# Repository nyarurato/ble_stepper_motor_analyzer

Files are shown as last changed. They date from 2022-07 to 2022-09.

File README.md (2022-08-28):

# BLE Stepper Motor Monitor

The BLE Stepper Monitor Analyzer is a variant of the Simple Stepper Motor Analyzer which replaces the touch screen LCD with a Bluetooth BLE radio link and a python app that provides the display or a desktop computer. This result in a smaller and less expensive board and a large display that leverages on the desktop computer capabilities.

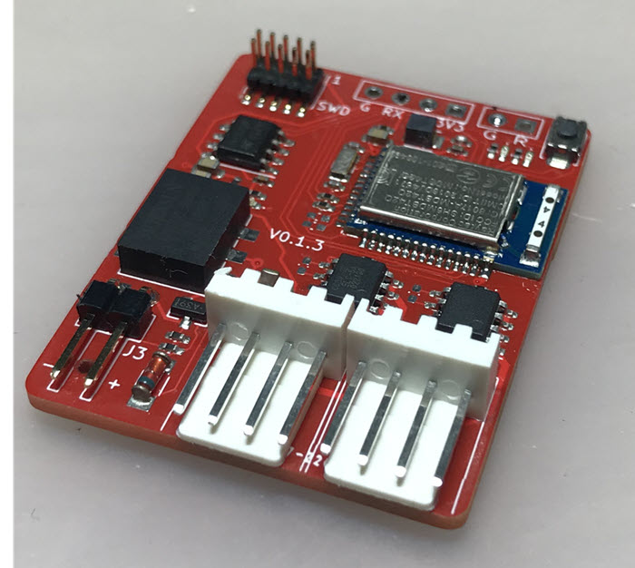
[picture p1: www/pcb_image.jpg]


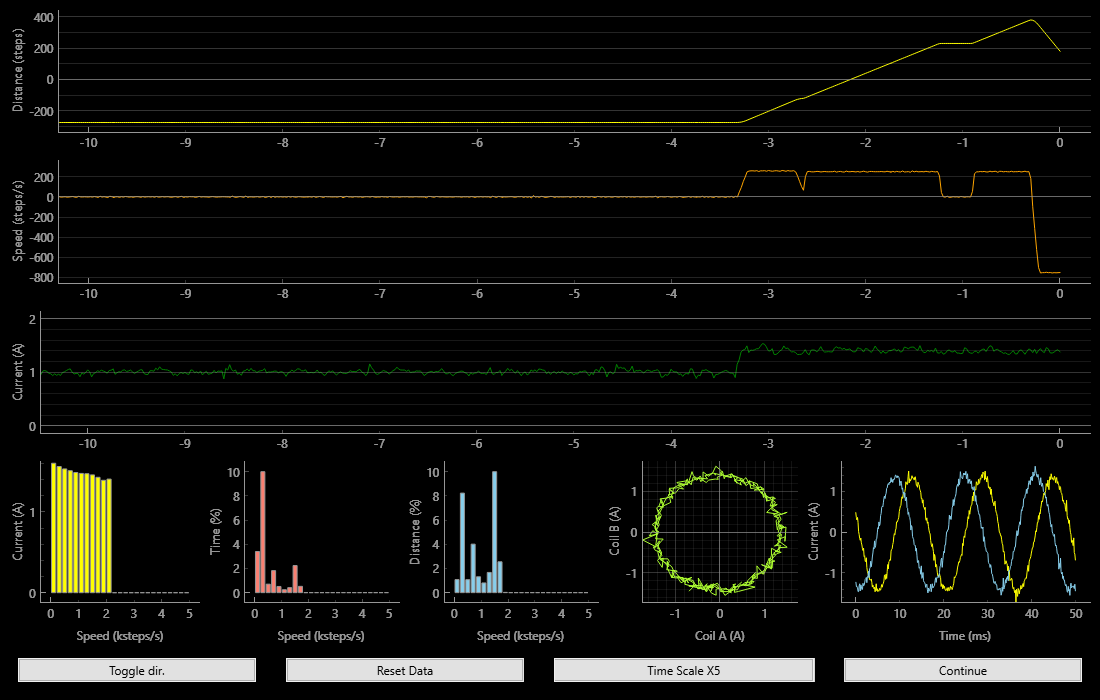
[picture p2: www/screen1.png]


## Highlights
* Open-source hardware, firmware, and software designs, with permissive license that allows commercial use and does not require attribution.
* A small and relatively inexpensive PCB that can be embedded in a 3D printer or CNC machine.
* Each PCB has a unique address and can be monitored individually.
* The PCB's can be ordered  from JLCPCB with all the parts preassembled, except for the the nrf52 BLE module that need to be soldered separately.
* The stepper motor is galvanically isolated from the analyzer's electronics which  minimizes potential interference or ground loops.
* The analyzer can be powered from any 4.5 to 30VDC source and consumes very little power, about 50mw. Even a single 9V battery can power it for many hours. Power is required only when monitoring the stepper and the stepper can be operates safely even if the PCB is not powered.

## Caveats
* At this time, updating the PCB firmware requires a programmer. Normally it can be an inexpensive Segger JLink EDU Mini, which as of Aug 2022 are unavailable due to the global supply chain shortage. A more expensive alternative is the Nordic nRF52832 DK which can act also as a Segger programmer.
* The two current sensor ICs that are available from JLCPCB have higher noise than the Alegro GMR sensors. However, the analyzer functions properly with the noisier sensors as well.
* As of Aug 2022, the python application requires some TLC, for example to recover gracefully if a wireless connection lost. However, it is fully functional and was tested on Windows and Mac OSX.
* The PCB can be built with two versions of the BLE module, one with an internal antenna and one with a U.FL connector for an external antenna. Internal antennas are 
more compact but may be insufficient with shielded 3D printers.

## Installing the PCB

* IMPORTANT: Always turn power off before connecting or disconnecting the PCB or the stepper motor.
* Connect a voltage of 4.5VDC t0 30VDC to the connector J3. Pay attention to polarity though the PCB is protected against reversed polarity. Verify that one red LED is solid while the other blinks slowly.;
* With the PCB energized and the **stepper not connected yet to the board** long press on the PCB button until the yellow LED will blink. Make sure the LED blinked exactly 3 times. This will calibrate the zero current of the sensors.
* With power off, connect the 4 wires of your stepper motor through the board such that one connector with four wires is connected to your controller and the other is connected to the stepper. The PCB is arranged such that the 4 connector pins from left to right are connected pass-through to their respective pins on the other connector. Also, the two connector are interchangeable such that each can act as an input or an output.
* Turn power on and verify that your machine functions properly and that the direction of the stepper is correct. That is, the wiring should not reverse the direction of the stepper.

## Installing and running the Python application.

1. Download the python directory this github repository.
1. Install python3 on your computer. Follow the Python installation instructions for your operating system. The analyzer requires Python 3.7 or latter but prefer the latest available python. 
1. Identify the *python* and *pip* command on your computer. On some computers they can be *python* and *pip* respectively and on others something like *python3.10& and *pip3.10* respectively. From now on we will refer to them as *python* and *pip* but replace with the actual command names as needed.
1. Verify the version of your python by running the command: **python --version**. Verify that the printed version number is at least 3.7.
1. With the PCB powered, Run the command  *python3 scanner_main.py*, after a few seconds, it will print a list of BLE devices it found. One of them should have the name that looks like STP-XXXXXXXXXXXX. Note the device
address that is printed before that name. We will use it later to access
the device.
1. Run the command **python analyzer_main.py -d <device-address>** where <device-address> is the device address you identified in the previous step. If you get errors about missing python modules such as **bleak**, install them using the pip command and try again. You can also use the
**requirements.txt** file to install all missing modules at once.
1. If everything went well, the analyzer_main.py application will connect to the device and shows its data in real time.

## Understanding the data
The screenshot below shows the 8 data items that are monitors. The data can be reset using the **Reset** button and can be paused/played using the **Pause/Continue** button. 

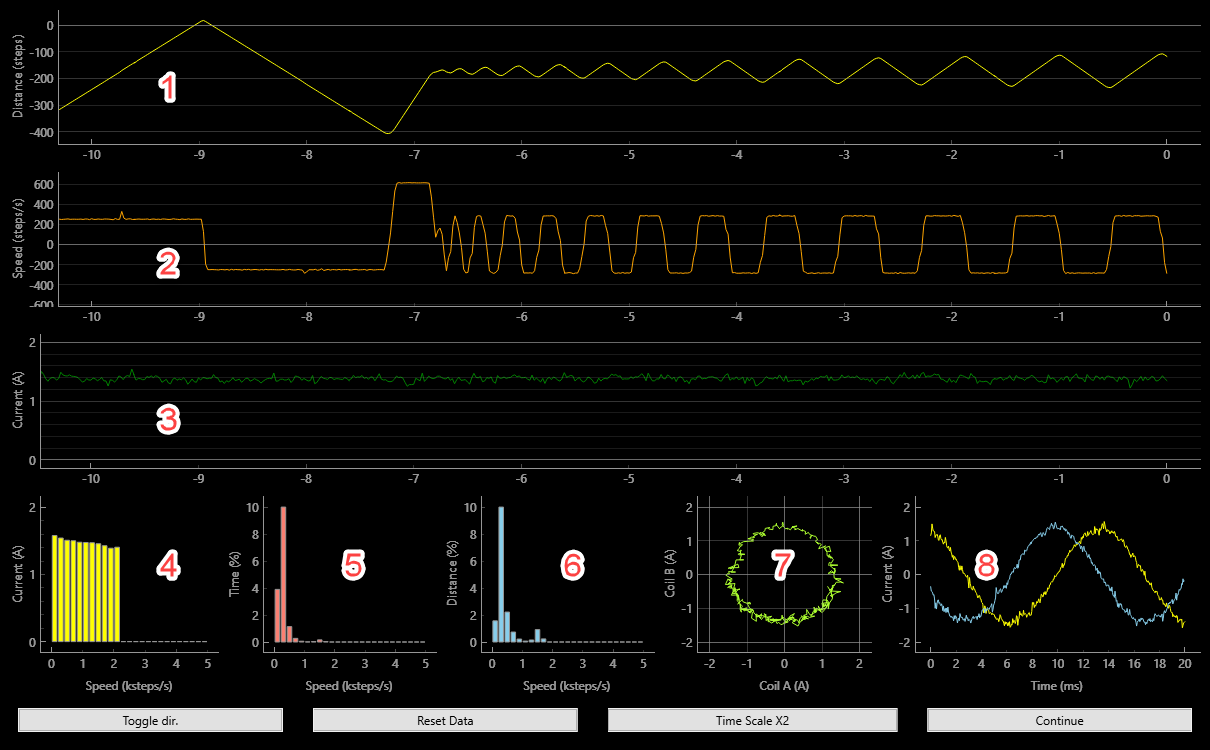
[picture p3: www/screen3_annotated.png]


1. Step counter over time. If the direction of the counting is opposite to what you would like, click on the **Toggle Dir** button. This will not effect the stepper motor but will count in the opposite direction.
2. Speed in steps/sec over time. This value is the derivative of the step counter above.
3. Stepper current in Amps over time. This value is computed as *sqrt(A^2 + B^2)* where A and B are the momentary currents in Amps in coils A, B respectively, and it represents the peak currents in each of the coils.
4. Coil peak current vs speed. This histogram shows the stepper current in different speeds. Ideally all speeds should have about the same current but too high inductance or too lower supply voltage may result in current and torque degradation in higher speeds.
5. Distance vs speed. This histogram shows in what speeds the stepper made the most distance (steps or revolutions)
6. Time vs speed. This histogram shows in what speeds the stepper was most of the time.
7. Phase pattern. This graph shows the 'cleanness' of the signal in the stepper coil. Every second of two the analyzer captures the signals in graph 8 and shows their pattern also in graph 7. Ideally graph 7 would be a circle center around the 0,0 point and its radius is the peak current set for the stepper.
8. Oscilloscope graph. This graph shows current patterns captures periodically from the two coils and ideally they should look like clean sin/cosine graphs with magnitude equal to the stepper peak current. Every cycle of the sin/cosine graph represent 4 full stepper steps. If the stepper speed is too fast or two slow to show the signals, use the Time Scale button to speed up or slow down the signal capture.

## Building your own BLE Stepper Motor Analyzer

* The three production files for JLCPCB SMD service are available under the kicad directory. This will allow you to get fully populated boards except for the BLE module.
* Solder a Raytac nrf52832 BLE module. You can use MDBT42Q-512KV2 (internal antenna) or MDBT42Q-U512KV2 (U.FL connector for an external antenna).
* Flash the board with the firmware using a compatible SWD programmer. We are using Segger's JLink with a Segger Edu Mini programmer or if this is not available, a Nordic NRF52-DK which can act also as a JLink programmer. Use a standard 2x5 pins 0.05" pitch SWD cable.
* Zero calibrate the sensors as explained above. 

## Modifying the firmware

* The source code of the firmware is available in this github repository under the platformio folder. Open that folder with the platformio IDE (a plugin for VSCode) and your project is ready.
* The PCB has a serial output for debugging. You can connect there a 115200 baud 3.3v serial/USB and view the output.
* To program the PCB use a Segger compatible debugger such as Segger Edu Mini, or Nordic nrf52 DK board. This will also allow you to debug the program, set breakpoints, single step and so on.

## FAQ

Q: Can I use this open source design in commercial products?

A: Yes, and you are welcome to do so, and attribution is not needed.

-----

Q: Can I operate the printer with the PCB connected but not powered or not monitored?

A: Yes. The electronics and the stepper are isolated from each other.

----

Q: How much does it cost to build the PCB?

A: Depending on quantities. For a batch of 30, JLCPCB changes about $7 per assembled board and then you need to add the Raytac BLE module which costs about $9. This brings the unit cost to less than $20, as of Aug 2022.

----

Q: If you would redesign it from scratch, what would you do differntly?

A: The main change would be to use ESP32 instead of the Raytac/Nordic module and this is for several reasons:

* It's less expensive.
* It has better support for firmware upgrade by the user.
* It's available from JLCPCB's SMD assembly service.

The Nordic nrf52 was selected for it's low power, with the intention to power the PCB by harvesting stepper motor power, but that requirement was dropped at a latter stages of the project.

-----

Q: How does this differs from the Simple Stepper Motor analyzer?

A: Some of the differences are:

* The lack of builtin display makes this analyzer more compact and less expensive.
* The Simple Stepper Motor analyzer is self contained with display while this one is intended to be buried in a 3D printer, using a computer for the display.
* The Simple Stepper Motor Analyzer uses a Raspberry Pi Pico processor while this one uses Nordic nRF52832.
* The Simple Stepper Motor Analyzer samples the signal at 100Khz while this one samples at 40Khz due to the limitations of the nRF52832. This however doesn't seem to matter.
* The Simple Stepper Motor Analyzer displays each graph on screen of its own while this one displays all the graphs at once.
* Having the display on a computer makes it easier to graph screenshots, for example, to post in diagnostics discussions in 3D printer forums.

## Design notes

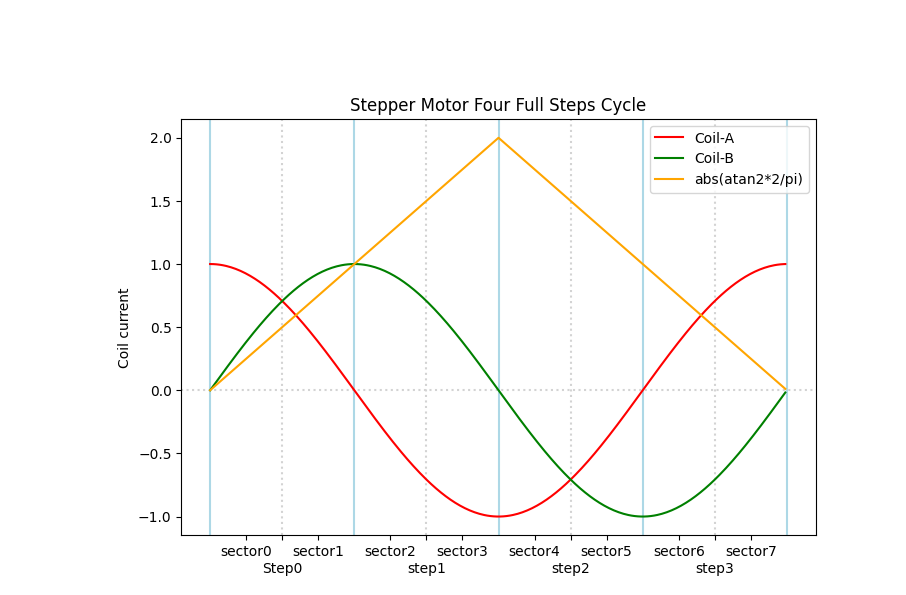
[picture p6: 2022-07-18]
docs/quadrants_plot.png

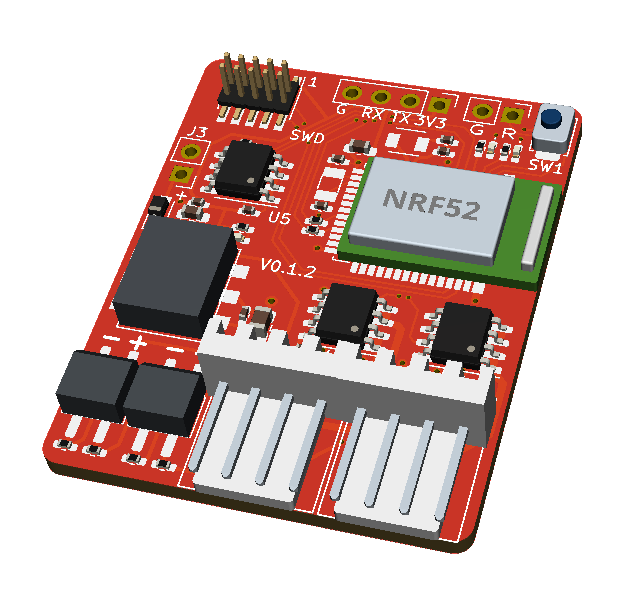
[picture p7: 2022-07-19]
docs/3d_view.png

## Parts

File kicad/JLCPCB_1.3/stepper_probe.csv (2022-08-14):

Comment | Designator | Footprint | LCSC
1u | C1 | stepper_probe:C_0402_1005Metric_Pad0.74x0.62mm_HandSolder | C52923
DNP | C13,C14 | stepper_probe:C_0402_1005Metric_Pad0.74x0.62mm_HandSolder | DNP
10u | C2,C10,C11 | stepper_probe:C_0603_1608Metric_Pad1.08x0.95mm_HandSolder | C96446
12pf | C3,C5 | stepper_probe:C_0402_1005Metric_Pad0.74x0.62mm_HandSolder | C26406
100n | C4,C6,C9,C12 | stepper_probe:C_0402_1005Metric_Pad0.74x0.62mm_HandSolder | C307331
10u 50v | C7 | stepper_probe:C_0805_2012Metric_Pad1.18x1.45mm_HandSolder | C440198
100n 50V | C8 | stepper_probe:C_0402_1005Metric_Pad0.74x0.62mm_HandSolder | C307331
LED Y | D2 | stepper_probe:LED_0402_1005Metric_Pad0.77x0.64mm_HandSolder | C165978
LED R | D1,D3 | stepper_probe:LED_0402_1005Metric_Pad0.77x0.64mm_HandSolder | C165980
5V6 | D4 | Diode_SMD:D_MiniMELF | C8062
Conn_01x04_Male | J1,J2 | stepper_probe:connector_4pins_horizontal | C31753
BAT | J3 | stepper_probe:PinHeader_1x02_P2.54mm_Horizontal_JLCPCB | C2935927
Serial Port | J4 | stepper_probe:PinHeader_1x04_P2.54mm_Vertical | DNP
SWD | J5 | stepper_probe:PinHeader_2x05_P1.27mm_Vertical_SMD | C2935458
Reset header | J6 | stepper_probe:PinHeader_1x02_P2.54mm_Vertical | DNP
10uh | L2 | stepper_probe:coil_10uh | C107342
15nh | L3 | stepper_probe:C_0402_1005Metric_Pad0.74x0.62mm_HandSolder | C27143
Motor | M1 | stepper_probe:Empty | DNP
PJA3439 | Q1 | stepper_probe:SOT-23_JLCPCB | C2844879
300k | R1 | stepper_probe:R_0402_1005Metric_Pad0.72x0.64mm_HandSolder | C25774
10K | R10 | stepper_probe:R_0402_1005Metric_Pad0.72x0.64mm_HandSolder | C25744
DNP | R11,R12 | stepper_probe:R_0402_1005Metric_Pad0.72x0.64mm_HandSolder | DNP
0R | R14,R15 | stepper_probe:R_0402_1005Metric_Pad0.72x0.64mm_HandSolder | C17168
20k | R2 | stepper_probe:R_0402_1005Metric_Pad0.72x0.64mm_HandSolder | C25765
5K1 | R5,R6,R7 | stepper_probe:R_0402_1005Metric_Pad0.72x0.64mm_HandSolder | C25905
1K | R8,R9,R16,R17 | stepper_probe:R_0402_1005Metric_Pad0.72x0.64mm_HandSolder | C11702
SW_Push | SW1 | stepper_probe:SW_Push_SPST_NO_Alps_SKRK | C720477
CC6920BSO-5A | U1,U2 | stepper_probe:SOIC-8_LCPCB_ROT | C2880430
MDBT42Q-512KV2 | U3 | stepper_probe:RAYTAC_MDBT42Q
K7803MT-500R4 | U4 | stepper_probe:Converter_DCDC | C2692194
M24C02-FMN | U5 | stepper_probe:SOIC-8_LCPCB_ROT | C7562
32.768Khz | Y1 | stepper_probe:Crystal_SMD_3215-2Pin_3.2x1.5mm | C479190

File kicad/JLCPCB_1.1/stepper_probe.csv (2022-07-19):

Comment | Designator | Footprint | LCSC
1u | C1 | stepper_probe:C_0402_1005Metric_Pad0.74x0.62mm_HandSolder | C52923
10u | C2,C10,C11 | stepper_probe:C_0603_1608Metric_Pad1.08x0.95mm_HandSolder | C96446
12pf | C3,C5 | stepper_probe:C_0402_1005Metric_Pad0.74x0.62mm_HandSolder | C26406
100n | C4,C6,C9,C12 | stepper_probe:C_0402_1005Metric_Pad0.74x0.62mm_HandSolder | C307331
10u 50v | C7 | stepper_probe:C_0805_2012Metric_Pad1.18x1.45mm_HandSolder | C440198
100n 50V | C8 | stepper_probe:C_0402_1005Metric_Pad0.74x0.62mm_HandSolder | C307331
LED Y | D2 | stepper_probe:LED_0402_1005Metric_Pad0.77x0.64mm_HandSolder | C165978
LED R | D1,D3 | stepper_probe:LED_0402_1005Metric_Pad0.77x0.64mm_HandSolder | C165980
MB1S | D4,D5 | stepper_probe:DIODE_BRIDGE | C232821
1N5819WS | D6 | stepper_probe:D_SOD-323_HandSoldering | C191023
Conn_01x04_Male | J1,J2 | stepper_probe:connector_4pins_horizontal
BAT | J3,J6 | stepper_probe:PinHeader_1x02_P2.54mm_Vertical
Serial Port | J4 | stepper_probe:PinHeader_1x04_P2.54mm_Vertical
SWD | J5 | stepper_probe:PinHeader_2x05_P1.27mm_Vertical_SMD | C2935458
10uh | L2 | stepper_probe:coil_10uh | C107342
15nh | L3 | stepper_probe:C_0402_1005Metric_Pad0.74x0.62mm_HandSolder | C27143
Motor | M1 | stepper_probe:Empty
10K | R10 | stepper_probe:R_0402_1005Metric_Pad0.72x0.64mm_HandSolder | C25744
10R | R1,R2,R3,R4 | stepper_probe:R_0402_1005Metric_Pad0.72x0.64mm_HandSolder | C25077
5K1 | R5,R6,R7 | stepper_probe:R_0402_1005Metric_Pad0.72x0.64mm_HandSolder | C25905
1K | R8,R9 | stepper_probe:R_0402_1005Metric_Pad0.72x0.64mm_HandSolder | C11702
SW_Push | SW1 | stepper_probe:SW_Push_SPST_NO_Alps_SKRK | C720477
TMCS1108A4BQDT | U1,U2 | Package_SO:SOIC-8_3.9x4.9mm_P1.27mm
MDBT42Q-512KV2 | U3 | stepper_probe:RAYTAC_MDBT42Q
K7803MT-500R4 | U4 | stepper_probe:Converter_DCDC | C2692194
M24C02-FMN | U5 | Package_SO:SOIC-8_3.9x4.9mm_P1.27mm | C7562
32.768Khz | Y1 | stepper_probe:Crystal_SMD_3215-2Pin_3.2x1.5mm | C479190

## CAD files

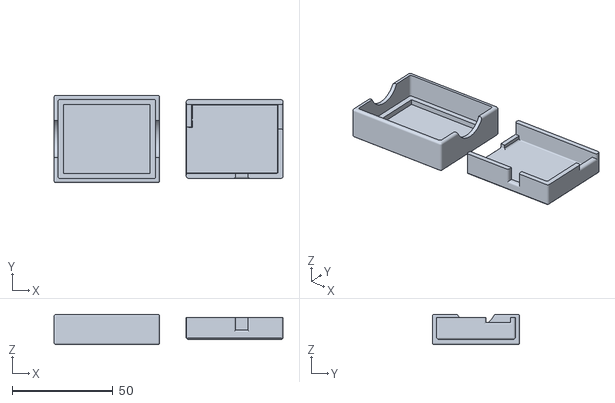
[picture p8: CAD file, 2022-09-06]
3D/ble_stepper_analyzer_case.stl
113.6 x 43.4 x 15.0

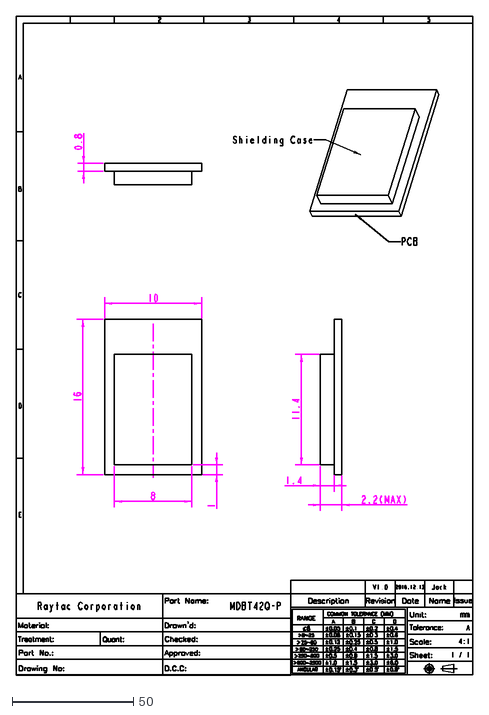
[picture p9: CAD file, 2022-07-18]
docs/MDBT42Q Footprint_Design Guide-210702/2D & 3D Drawing/MDBT42Q-P/MDBT42Q-P 2D Drawing-20170503.dxf
188.5 x 271.9

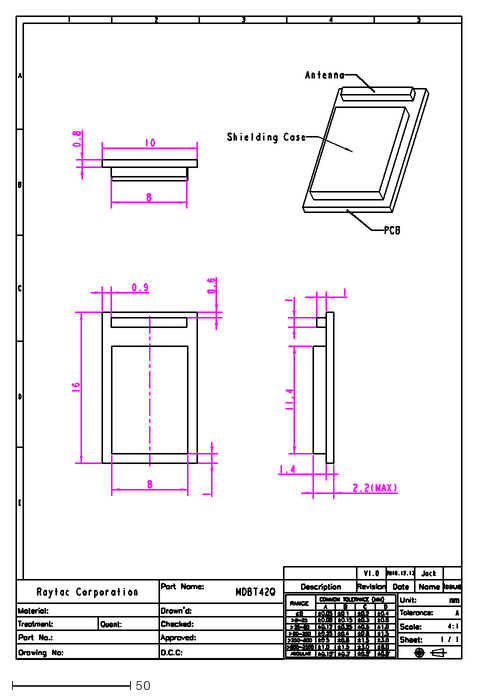
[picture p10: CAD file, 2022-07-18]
docs/MDBT42Q Footprint_Design Guide-210702/2D & 3D Drawing/MDBT42Q/MDBT42Q 2D Drawing-20170503.dxf
188.5 x 271.9

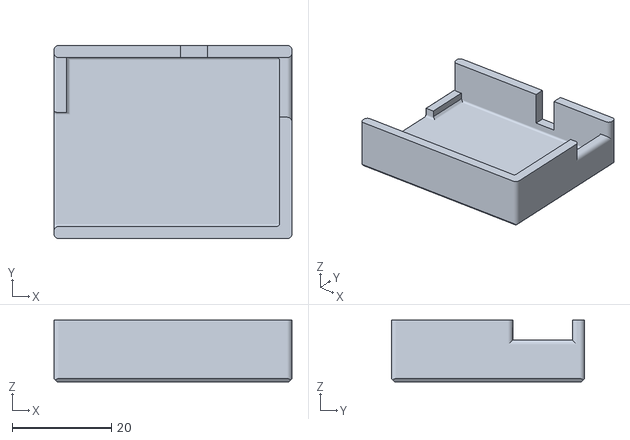
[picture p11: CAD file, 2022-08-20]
docs/stepper_probe_case.stl
48.0 x 39.0 x 12.5

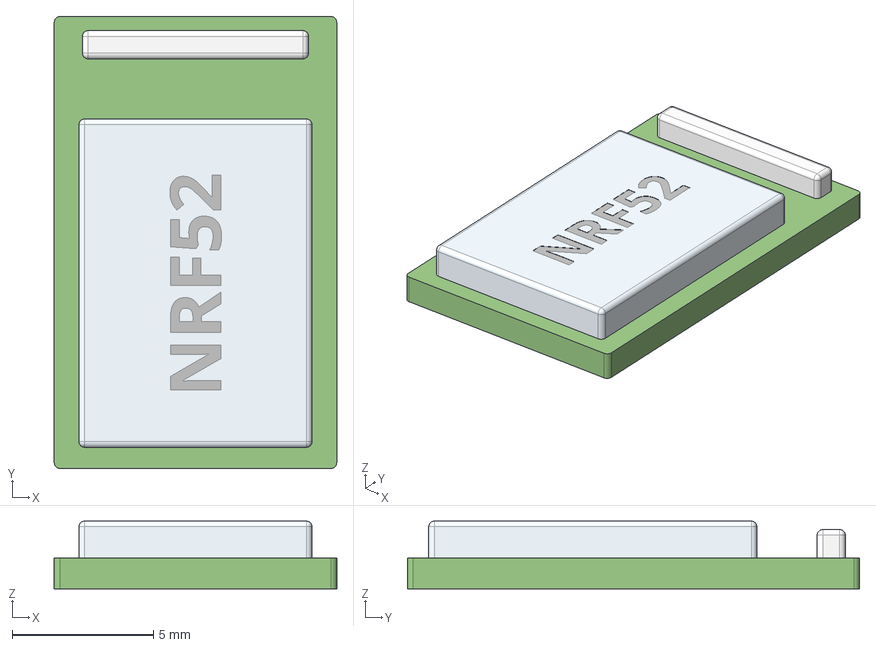
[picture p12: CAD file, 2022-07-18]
kicad/models/raytack_MDBT42Q.step
10.0 x 16.0 x 2.40 mm

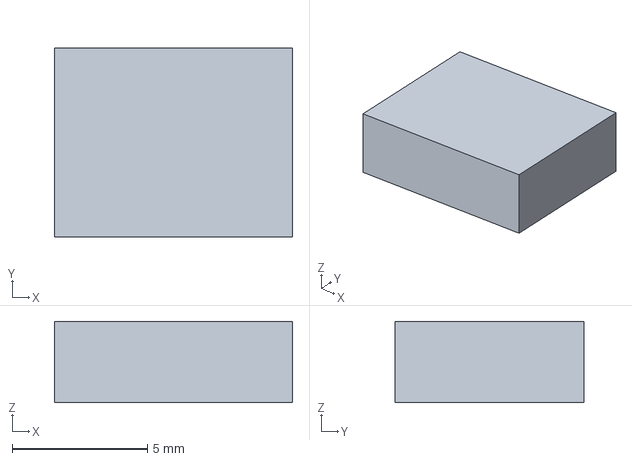
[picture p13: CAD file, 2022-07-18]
kicad/models/dc_dc_model.step
8.80 x 7.00 x 3.00 mm

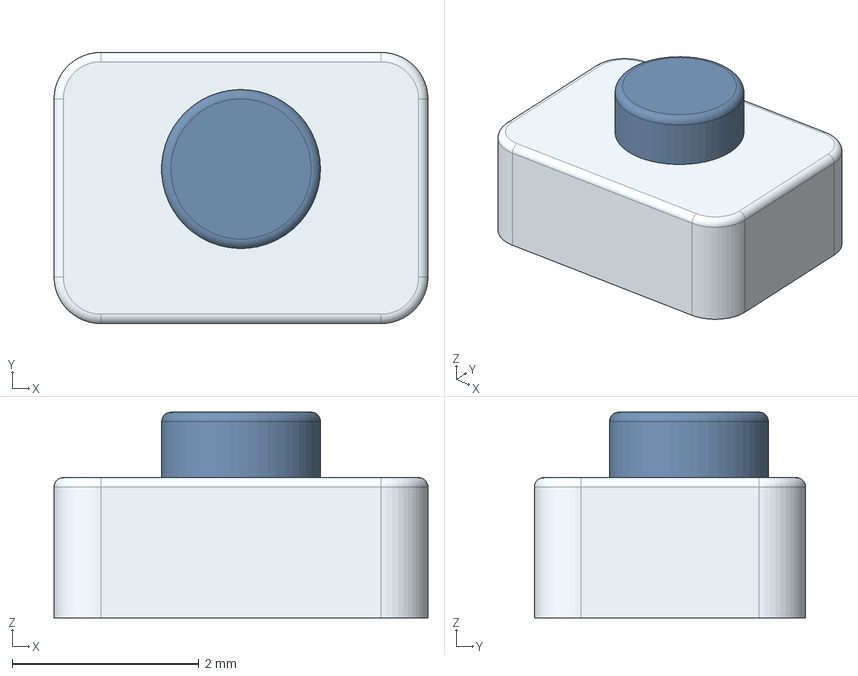
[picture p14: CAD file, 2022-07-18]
kicad/models/tactile_switch.step
4.00 x 2.90 x 2.20 mm

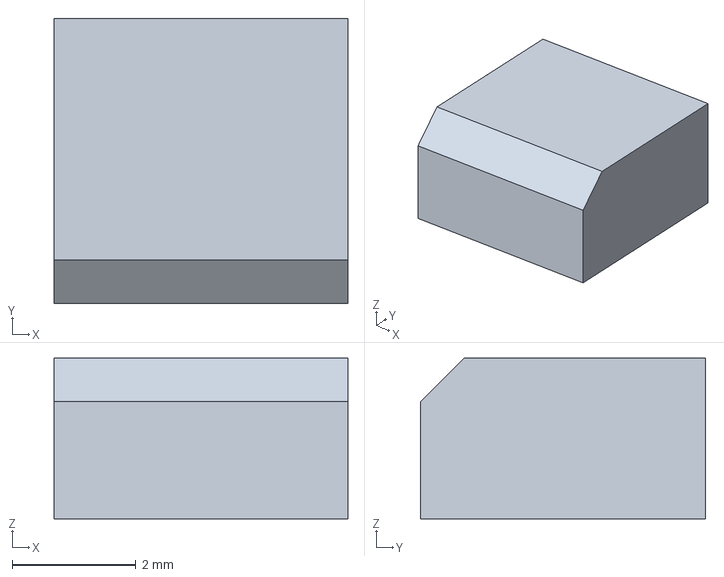
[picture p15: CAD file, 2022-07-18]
kicad/models/diode_bridge.step
4.75 x 4.60 x 2.60 mm

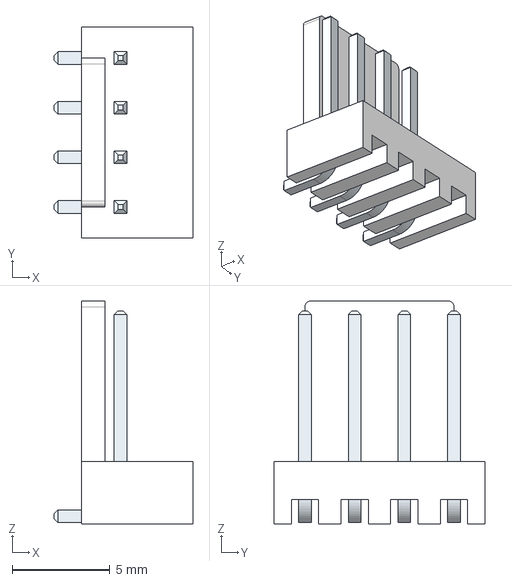
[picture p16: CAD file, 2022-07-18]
kicad/models/kf2510_4p_right_angle.step
7.10 x 10.8 x 11.4 mm

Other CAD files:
docs/MDBT42Q Footprint_Design Guide-210702/2D & 3D Drawing/MDBT42Q-P/MDBT42Q-P 2D Drawing-20170503.dwg
docs/MDBT42Q Footprint_Design Guide-210702/2D & 3D Drawing/MDBT42Q/MDBT42Q 2D Drawing-20170503.dwg

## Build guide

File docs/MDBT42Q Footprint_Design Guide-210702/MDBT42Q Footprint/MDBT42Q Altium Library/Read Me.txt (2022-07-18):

Files are compatible with Altium Designer 09

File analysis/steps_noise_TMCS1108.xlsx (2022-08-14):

Raw Steps | Normalized Steps | Normalized Squared
0.37 | 0.003592814371 | 1.290831511e-05
0.39 | 0.02 | 0.0006
0.36 | -0.01 | 4.105202768e-05
0.35 | -0.02 | 0.0003
0.37 | 0.003592814371 | 1.290831511e-05
0.41 | 0.04 | 0.0019
0.41 | 0.04 | 0.0019
0.38 | 0.01 | 0.0002
0.37 | 0.003592814371 | 1.290831511e-05
0.40 | 0.03 | 0.0011
0.35 | -0.02 | 0.0003
0.38 | 0.01 | 0.0002
0.40 | 0.03 | 0.0011
0.38 | 0.01 | 0.0002
0.36 | -0.01 | 4.105202768e-05
0.35 | -0.02 | 0.0003
0.35 | -0.02 | 0.0003
0.36 | -0.01 | 4.105202768e-05
0.36 | -0.01 | 4.105202768e-05
0.38 | 0.01 | 0.0002
0.34 | -0.03 | 0.0007
0.36 | -0.01 | 4.105202768e-05
0.38 | 0.01 | 0.0002
0.37 | 0.003592814371 | 1.290831511e-05
0.36 | -0.01 | 4.105202768e-05
0.40 | 0.03 | 0.0011
0.37 | 0.003592814371 | 1.290831511e-05
0.37 | 0.003592814371 | 1.290831511e-05
0.36 | -0.01 | 4.105202768e-05
0.35 | -0.02 | 0.0003
0.37 | 0.003592814371 | 1.290831511e-05
0.38 | 0.01 | 0.0002
0.39 | 0.02 | 0.0006
0.37 | 0.003592814371 | 1.290831511e-05
0.38 | 0.01 | 0.0002
0.38 | 0.01 | 0.0002
0.36 | -0.01 | 4.105202768e-05
0.38 | 0.01 | 0.0002
0.37 | 0.003592814371 | 1.290831511e-05
0.35 | -0.02 | 0.0003
0.38 | 0.01 | 0.0002
0.36 | -0.01 | 4.105202768e-05
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

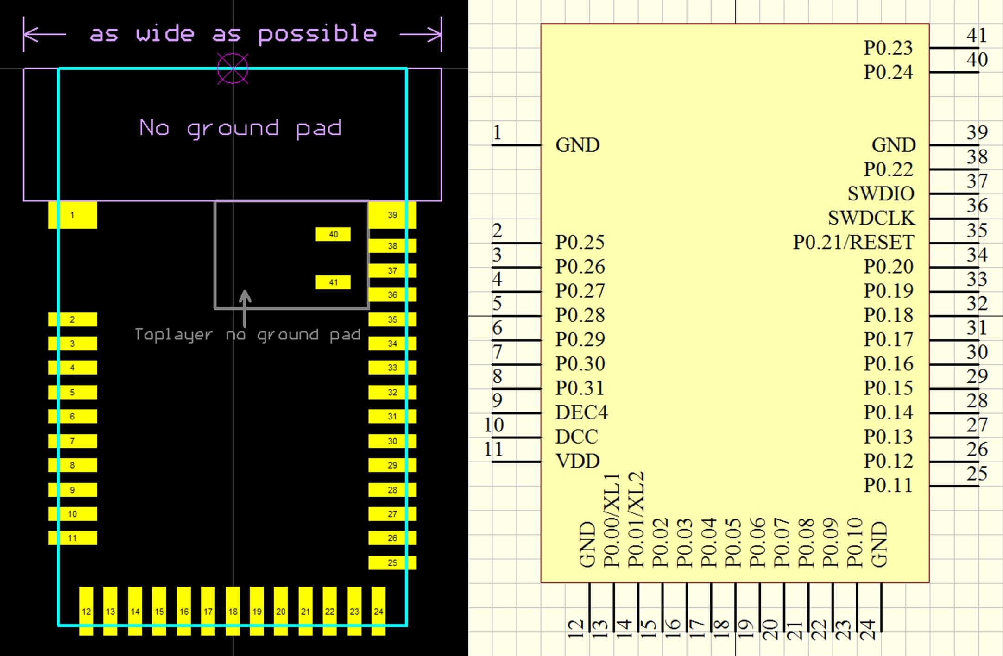
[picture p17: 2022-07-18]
docs/MDBT42Q Footprint_Design Guide-210702/MDBT42Q Footprint/MDBT42Q Protel Library/MDBT42Q Protel Library-210702.jpg

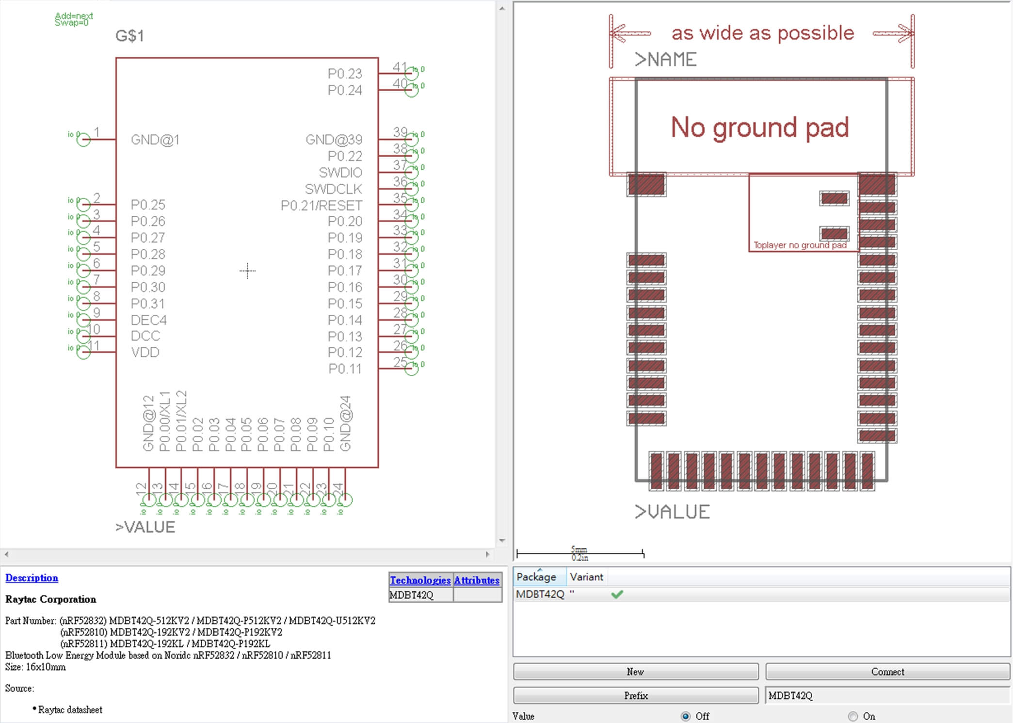
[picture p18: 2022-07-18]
docs/MDBT42Q Footprint_Design Guide-210702/MDBT42Q Footprint/MDBT42Q Eagle Library/MDBT42Q Eagle Library-210702.jpg

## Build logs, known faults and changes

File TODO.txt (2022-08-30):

* [Device] Avoid step counter drift when stepper is not energized.

* [Python] Add text display of steps and currents.

---------------

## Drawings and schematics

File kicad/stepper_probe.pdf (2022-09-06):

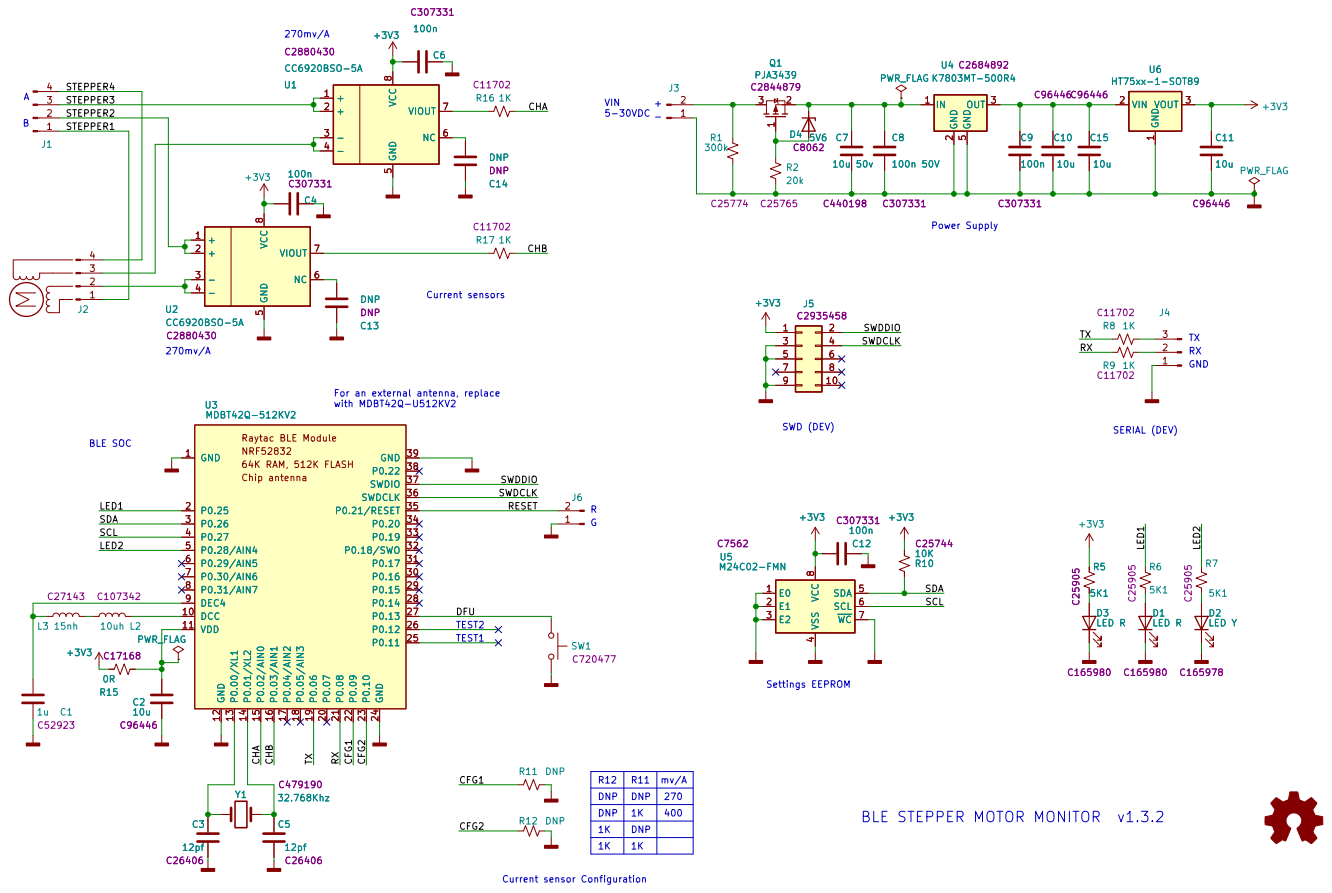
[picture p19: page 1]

For an external antenna, replace with MDBT42Q-U512KV2

4 SDA 5 SCL 6 ~{WC} 7 VCC

270 mv/A DNP

1K | 400 DNP

BLE STEPPER MOTOR MONITOR v1.3.2

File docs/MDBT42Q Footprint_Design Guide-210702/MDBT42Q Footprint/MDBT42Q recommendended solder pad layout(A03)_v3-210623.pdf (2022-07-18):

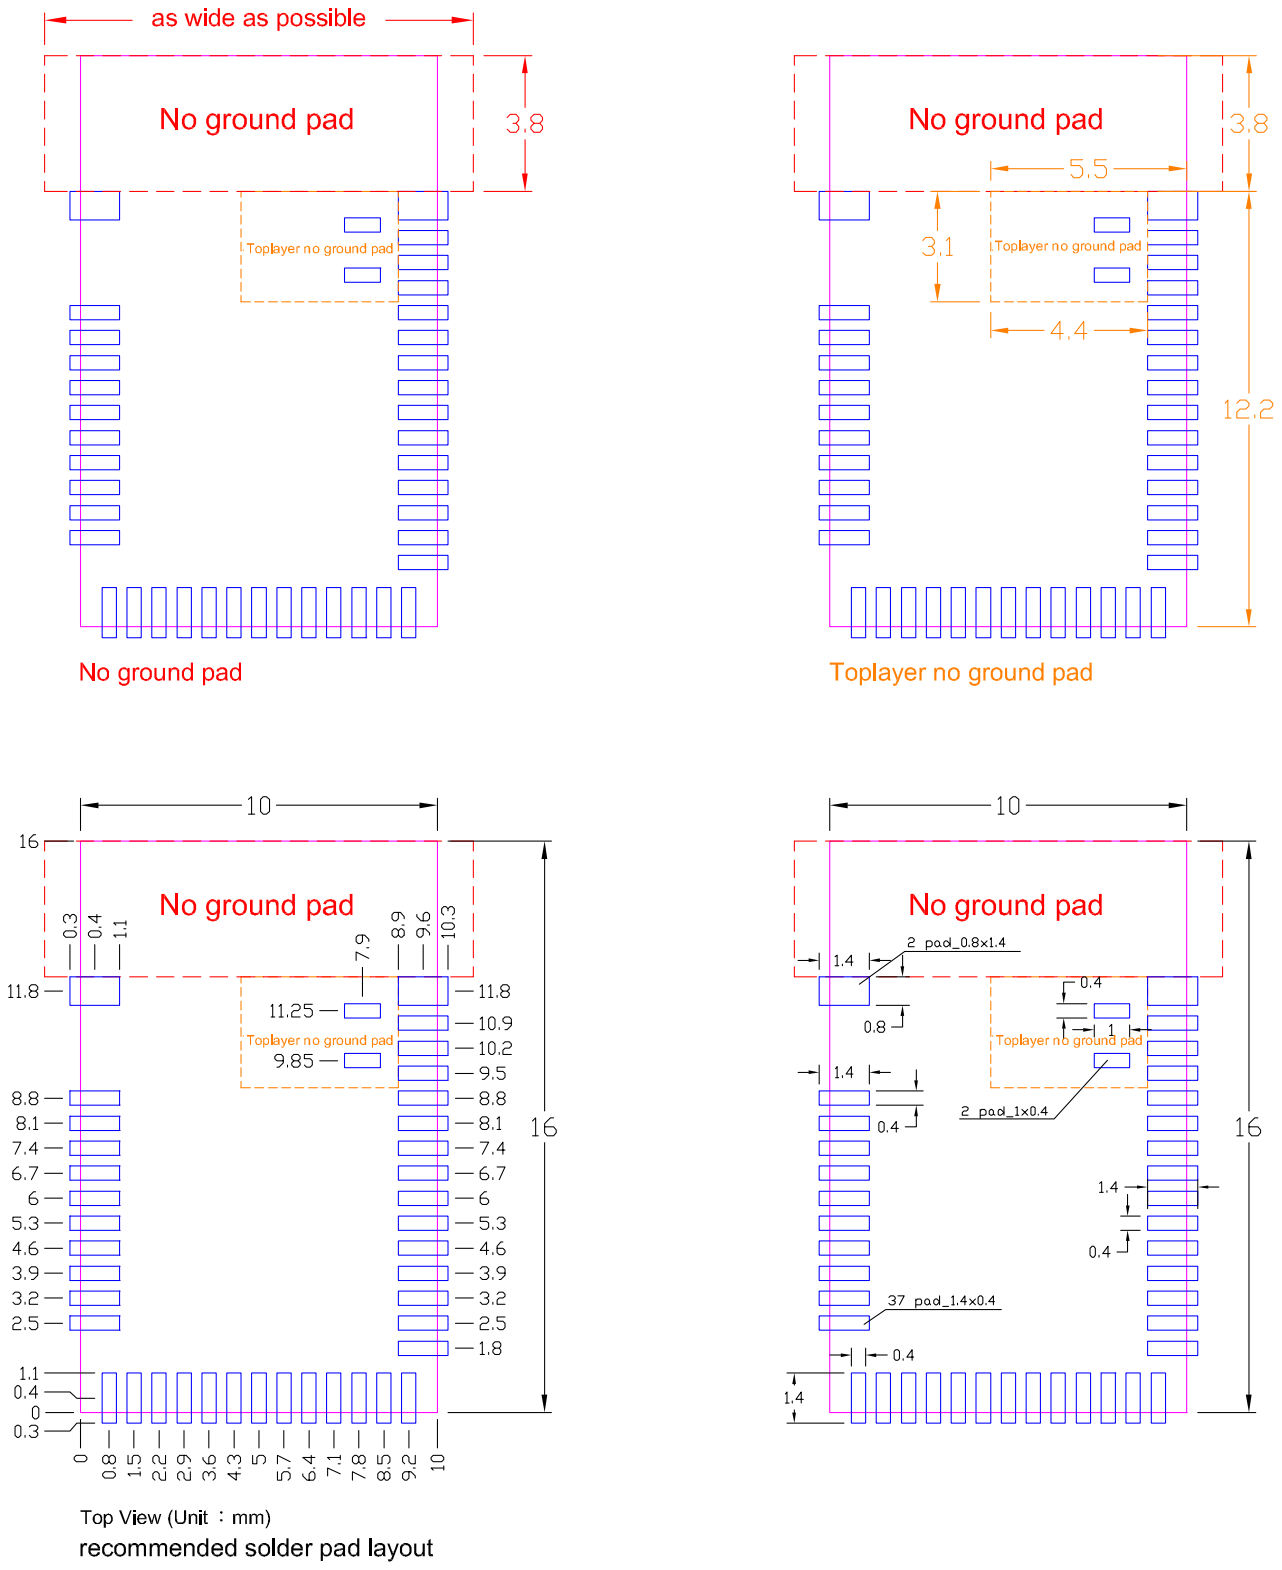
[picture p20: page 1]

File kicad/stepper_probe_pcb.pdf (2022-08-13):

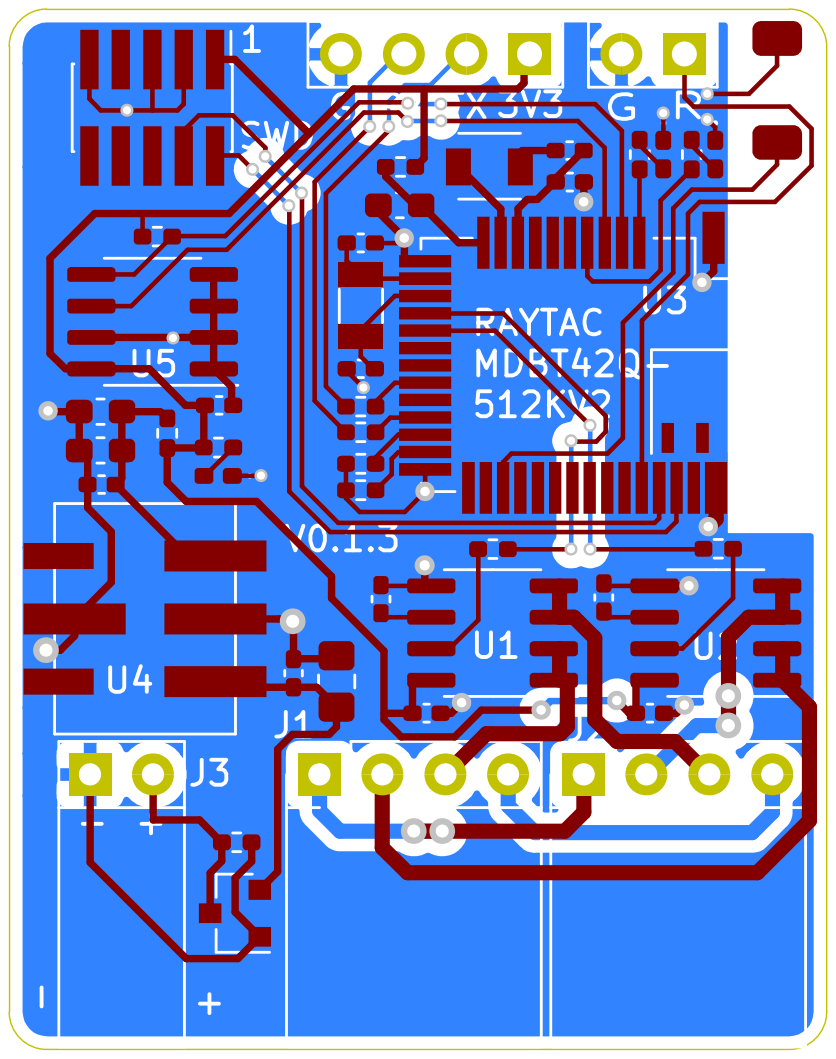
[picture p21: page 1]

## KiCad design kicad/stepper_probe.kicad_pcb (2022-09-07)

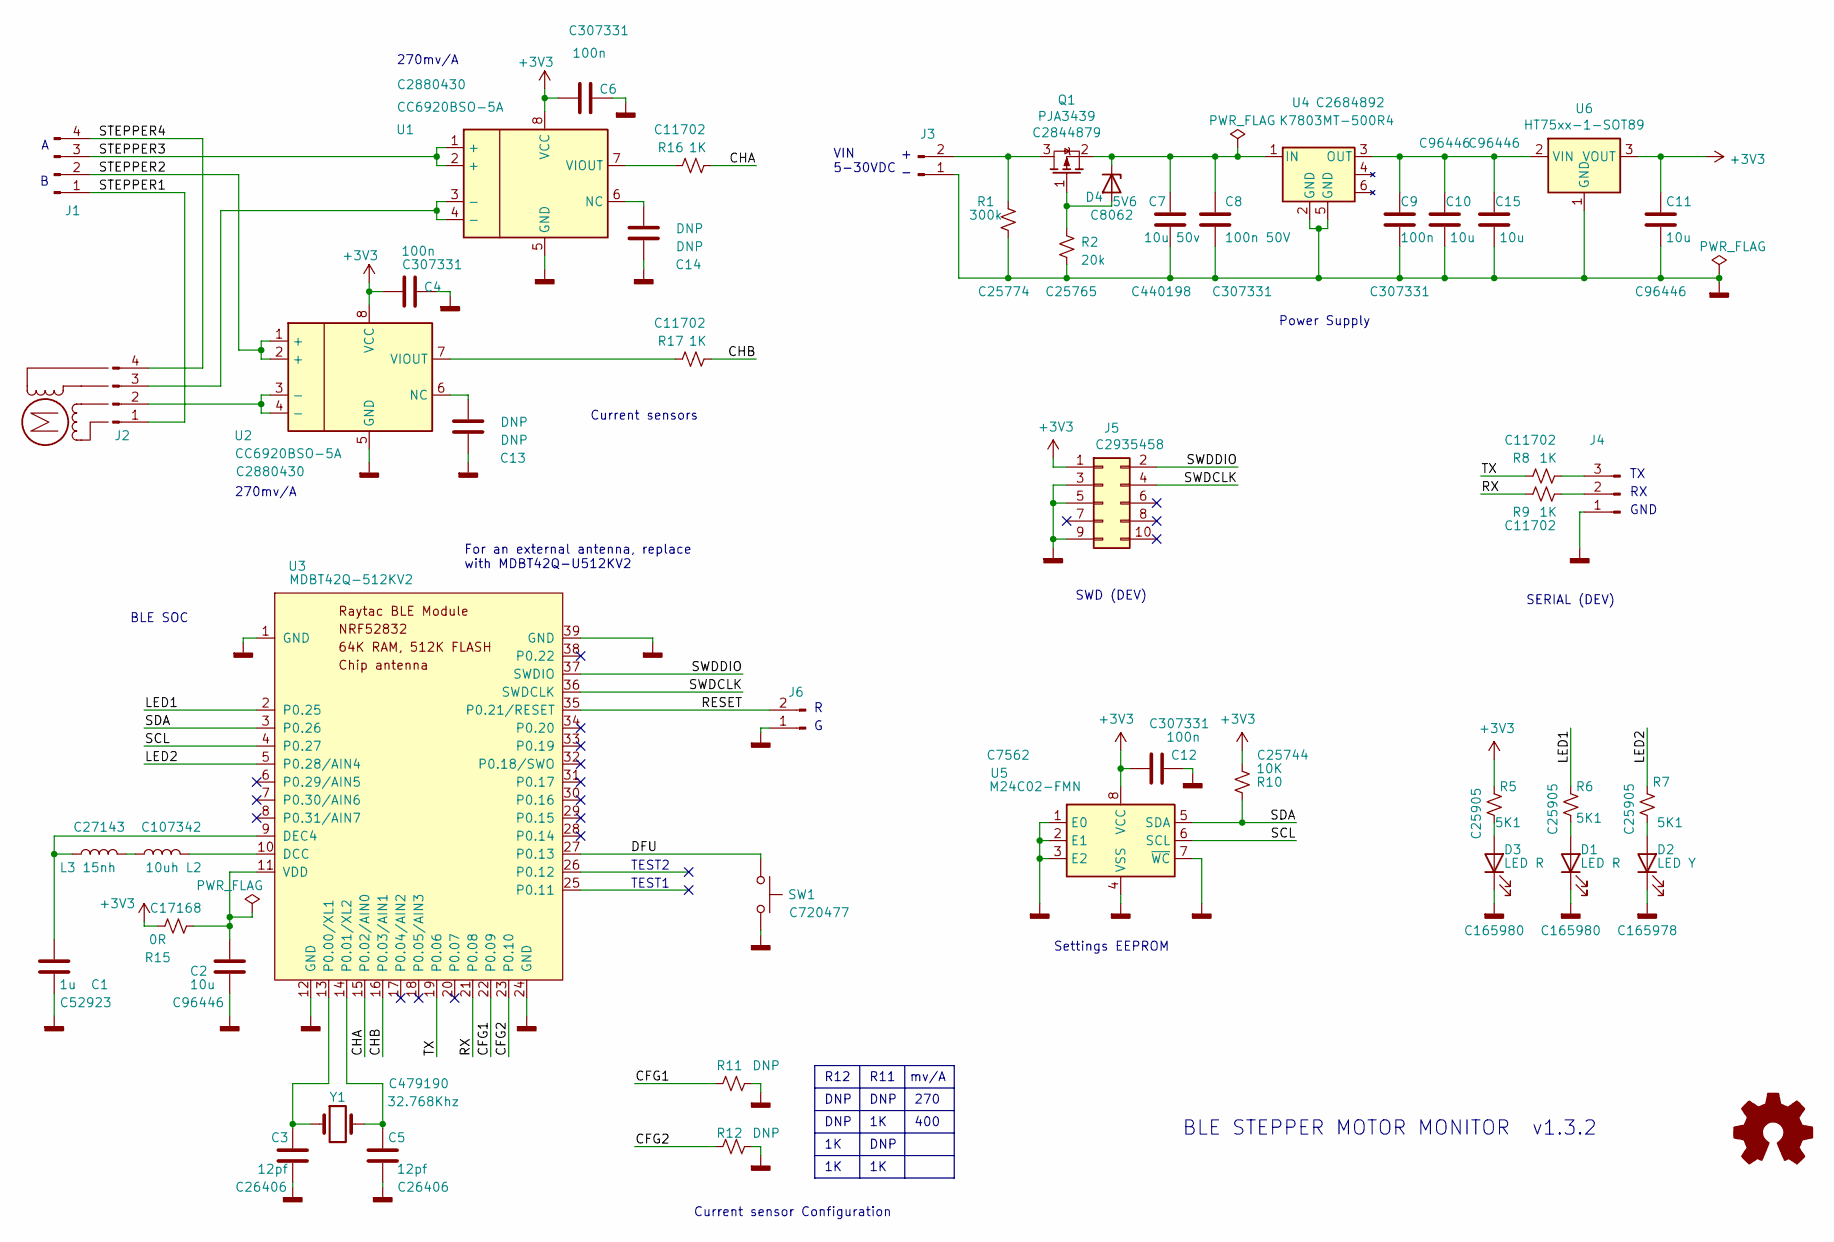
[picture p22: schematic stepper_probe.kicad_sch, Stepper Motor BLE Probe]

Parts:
C1: 1u; C_0402_1005Metric_Pad0.74x0.62mm_HandSolder; LCSC C52923
C2, C10, C11, C15: 10u; C_0603_1608Metric_Pad1.08x0.95mm_HandSolder; LCSC C96446
C3, C5: 12pf; C_0402_1005Metric_Pad0.74x0.62mm_HandSolder; LCSC C26406
C4, C6, C9, C12: 100n; C_0402_1005Metric_Pad0.74x0.62mm_HandSolder; LCSC C307331
C7: 10u 50v; C_0805_2012Metric_Pad1.18x1.45mm_HandSolder; LCSC C440198
C8: 100n 50V; C_0402_1005Metric_Pad0.74x0.62mm_HandSolder; LCSC C307331
C13, C14: DNP; C_0402_1005Metric_Pad0.74x0.62mm_HandSolder; LCSC DNP
D1, D3: LED R; LED_0402_1005Metric_Pad0.77x0.64mm_HandSolder; LCSC C165980
D2: LED Y; LED_0402_1005Metric_Pad0.77x0.64mm_HandSolder; LCSC C165978
D4: 5V6; D_MiniMELF_zenner; LCSC C8062
J1, J2: Conn_01x04_Male; connector_4pins_horizontal; LCSC C31753
J3: BAT; PinHeader_1x02_P2.54mm_Horizontal_JLCPCB; LCSC C2935927
J4: Conn_01x03_Male; PinHeader_1x03_P2.54mm_Vertical; LCSC C49257
J5: SWD; PinHeader_2x05_P1.27mm_Vertical_SMD; LCSC C2935458
J6: Reset header; PinHeader_1x02_P2.54mm_Vertical; LCSC DNP
L2: 10uh; coil_10uh; LCSC C107342
L3: 15nh; C_0402_1005Metric_Pad0.74x0.62mm_HandSolder; LCSC C27143
M1: Motor; Empty; LCSC DNP
Q1: PJA3439; SOT-23_JLCPCB; LCSC C2844879
R1: 300k; R_0402_1005Metric_Pad0.72x0.64mm_HandSolder; LCSC C25774
R2: 20k; R_0402_1005Metric_Pad0.72x0.64mm_HandSolder; LCSC C25765
R5, R6, R7: 5K1; R_0402_1005Metric_Pad0.72x0.64mm_HandSolder; LCSC C25905
R8, R9, R16, R17: 1K; R_0402_1005Metric_Pad0.72x0.64mm_HandSolder; LCSC C11702
R10: 10K; R_0402_1005Metric_Pad0.72x0.64mm_HandSolder; LCSC C25744
R11, R12: DNP; R_0402_1005Metric_Pad0.72x0.64mm_HandSolder; LCSC DNP
R15: 0R; R_0402_1005Metric_Pad0.72x0.64mm_HandSolder; LCSC C17168
SW1: SW_Push; SW_Push_SPST_NO_Alps_SKRK; LCSC C720477
U1, U2: CC6920BSO-5A; SOIC-8_LCPCB_ROT; LCSC C2880430
U3: MDBT42Q-512KV2; RAYTAC_MDBT42Q
U4: K7803MT-500R4; Converter_DCDC; LCSC C2684892
U5: M24C02-FMN; SOIC-8_LCPCB_ROT; LCSC C7562
U6: HT75xx-1-SOT89; SOT-89-3; LCSC C14289
Y1: 32.768Khz; Crystal_SMD_3215-2Pin_3.2x1.5mm; LCSC C479190

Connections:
+3V3: C4.2, C6.2, C11.1, C12.2, J5.1, R5.2, R10.2, R15.2, U1.8 (VCC), U2.8 (VCC), U5.8 (VCC), U6.3 (VOUT)
/CFG1: R11.1, U3.22 (P0.09)
/CFG2: R12.1, U3.23 (P0.10)
/CHA: R16.1, U3.15 (P0.02/AIN0)
/CHB: R17.1, U3.16 (P0.03/AIN1)
/DFU: SW1.1, U3.27 (P0.13)
/LED1: R6.2, U3.2 (P0.25)
/LED2: R7.2, U3.5 (P0.28/AIN4)
/RESET: J6.2, U3.35 (P0.21/RESET)
/RX: R9.2, U3.21 (P0.08)
/SCL: U3.4 (P0.27), U5.6 (SCL)
/SDA: R10.1, U3.3 (P0.26), U5.5 (SDA)
/STEPPER1: J1.1, J2.1
/STEPPER2: J1.2, U2.1 (+), U2.2 (+)
/STEPPER3: J1.3, U1.1 (+), U1.2 (+)
/STEPPER4: J1.4, J2.4
/SWDCLK: J5.4, U3.36 (SWDCLK)
/SWDDIO: J5.2, U3.37 (SWDIO)
/TX: R8.2, U3.19 (P0.06)
GND: C1.2, C2.2, C3.2, C4.1, C5.2, C6.1, C7.2, C8.2, C9.2, C10.2, C11.2, C12.1, C13.1, C14.1, C15.2, D1.1 (K), D2.1 (K), D3.1 (K), J3.1, J4.1, J5.3, J5.5, J5.9, J6.1, R1.1, R2.1, R11.2, R12.2, SW1.2, U1.5 (GND), U2.5 (GND), U3.1 (GND), U3.12 (GND), U3.24 (GND), U3.39 (GND), U4.2 (GND), U4.5 (GND), U5.1 (E0), U5.2 (E1), U5.3 (E2), U5.4 (VSS), U5.7 (~WC), U6.1 (GND)
unnamed: C1.1, L3.2, U3.9 (DEC4)
unnamed: C2.1, R15.1, U3.11 (VDD)
unnamed: C3.1, U3.13 (P0.00/XL1), Y1.1
unnamed: C5.1, U3.14 (P0.01/XL2), Y1.2
unnamed: C7.1, C8.1, D4.1 (K), Q1.2 (S), U4.1 (IN)
unnamed: C9.1, C10.1, C15.1, U4.3 (OUT), U6.2 (VIN)
unnamed: C13.2, U2.6 (NC)
unnamed: C14.2, U1.6 (NC)
unnamed: D1.2 (A), R6.1
unnamed: D2.2 (A), R7.1
unnamed: D3.2 (A), R5.1
unnamed: D4.2 (A), Q1.1 (G), R2.2
unnamed: J2.2, U2.3 (-), U2.4 (-)
unnamed: J2.3, U1.3 (-), U1.4 (-)
unnamed: J3.2, Q1.3 (D), R1.2
unnamed: J4.2, R9.1
unnamed: J4.3, R8.1
unnamed: L2.1, U3.10 (DCC)
unnamed: L2.2, L3.1
unnamed: R16.2, U1.7 (VIOUT)
unnamed: R17.2, U2.7 (VIOUT)

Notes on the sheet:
VIN 5-30VDC
270mv/A
mv/A
Current sensor Configuration
DNP
270
TEST2
BLE SOC
Power Supply
Settings EEPROM
SWD (DEV)
For an external antenna, replace with MDBT42Q-U512KV2
R12
TEST1
400
GND
R11
Current sensors
BLE STEPPER MOTOR MONITOR v1.3.2
SERIAL (DEV)

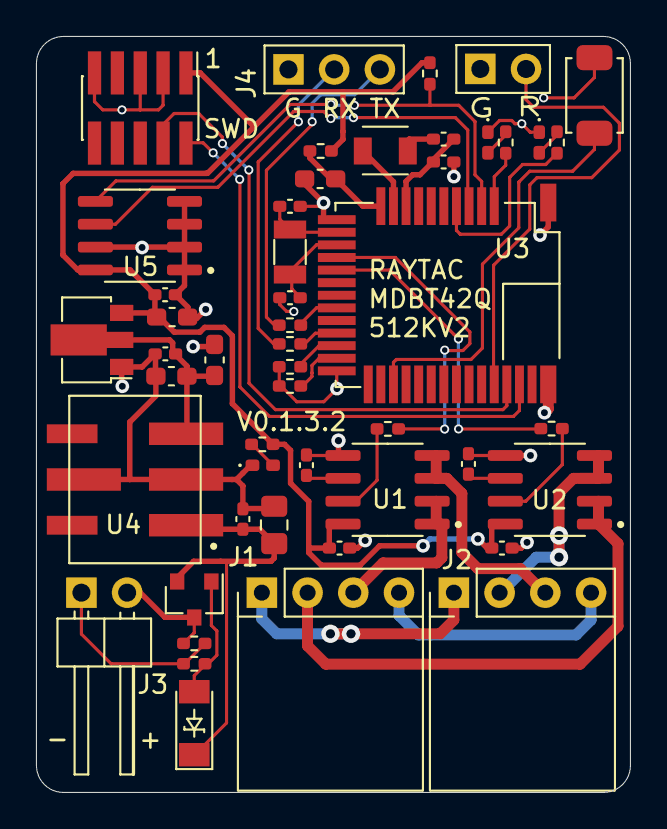
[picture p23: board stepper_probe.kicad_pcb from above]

Board: 2 copper layers, 33.0 x 42.0 mm, 50 parts (0 on the bottom side), 41 nets.

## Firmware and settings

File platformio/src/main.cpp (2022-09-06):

#include <bluetooth/gatt.h>
#include <errno.h>
#include <stdio.h>
#include <string.h>
#include <sys/printk.h>
#include <zephyr.h>
#include <zephyr/types.h>

#include "acquisition/adc_dma.h"
#include "acquisition/analyzer.h"
#include "ble/ble_service.h"
#include "ble/ble_util.h"
#include "misc/button.h"
#include "misc/config_eeprom.h"
#include "misc/controls.h"
#include "misc/elapsed.h"
#include "misc/io.h"
#include "misc/util.h"

// NOTE: UUID are version 4 (random) UUID, generated
// at https://www.uuidgenerator.net.

//-----------------------------------

static Elapsed periodic_timer;

// TODO: share with other temp state buffers
static analyzer::State notification_state;

// When true, blinking LED is solid to provide feedback.
// static bool zero_setting = false;

// Used to have solid LED for a short time after reset to
// indicate a reset, in case of an unstable power supply.
// static bool reset_flag = true;

// Used to blink N times LED 2.
static Elapsed led2_timer;
// Down counter. If value > 0, then led2 blinks and bit 0 controls
// the led state.
static uint16_t led2_counter;

static void start_led2_blinks(uint16_t n) {
  led2_timer.reset();
  led2_counter = n * 2;
  io::LED2.write(led2_counter > 0);
}

// Determine hardware configuration based on configuration
// resistors.
static uint16_t get_adc_ticks_per_amp(uint8_t hardware_config) {
  switch (hardware_config) {
    case 3:
    case 0:  // For broken nrf52 boards.
      // R12, R11 not installed.
      return acq_consts::CC6920BSO5A_MV_PER_AMP;
      break;
    case 2:
      // Only R11 is installed.
      return acq_consts::TMCS1108A4B_MV_PER_AMP;
      break;
    // Configurations 0, 1 are reserved.
    default:
      printk("ERROR: Unknoen hardware config %hhu\n", hardware_config);
      return 0;
  }
}

static void aqc_setup() {
  analyzer::Settings settings;
  config_eeprom::read_acquisition_settings(&settings);

  // NOTE that we call the analyzer settings before starting
  // the ADC interrupts.
  analyzer::setup(settings);

  adc_dma::setup();
}

// static void input_test() {
//   nrf_gpio_cfg_output(25);
//   nrf_gpio_pin_write(25, 1);

//   // const uint32_t pin_num_ = 10;
//   const uint32_t pin_num_ = 9;
//   // const uint32_t pin_num_ = 5;
//   // const uint32_t pin_num_ = 7;
//   nrf_gpio_cfg_input(pin_num_, NRF_GPIO_PIN_PULLUP);

//   for (;;) {
//     k_msleep(500);
//     nrf_gpio_cfg_input(pin_num_, NRF_GPIO_PIN_PULLUP);
//     uint32_t val = nrf_gpio_pin_read(pin_num_);
//     nrf_gpio_pin_write(25, val > 0);
//   }
// }

// Used to generate blink to indicates that
// acquisition is working.
static uint32_t analyzer_counter = 0;

// class A {
//   public:
//     A(int val): val_(val) {}
//     int val_;
// };

// A a1(11);
// int b = 123;

// extern "C" void __libc_init_array();

void main(void) {
  // __libc_init_array();
  // for(;;) {
  //   A a2(22);
  //   printk("a1.val_=%d, a2.val_=%d, b=%d\n", a1.val_, a2.val_, b);
  //     k_msleep(500);
  // }

  // input_test();

  io::setup();
  button::setup();
  util::dump_zephyr_devices();

  // We assume that the pullup inputs got settled by now.
  const uint8_t hardware_config = io::read_hardware_config();
  printk("Hardware config: %hhu\n", hardware_config);
  const uint16_t adc_ticks_per_amp = get_adc_ticks_per_amp(hardware_config);
  printk("ADC ticks per amp: %hu\n", adc_ticks_per_amp);

  ble_service::setup(hardware_config, adc_ticks_per_amp);
  aqc_setup();

  static bool is_connected = false;
  for (;;) {
    // Update is_connected periodically.
    if (periodic_timer.elapsed_millis() >= 500) {
      periodic_timer.reset();
      is_connected = ble_service::is_connected();
    }

    // Update LED blinks.  Blinking indicates analyzer works
    // and provides states. High speed blink indicates connection
    // status.
    const int blink_shift = is_connected ? 0 : 3;
    const bool blink_state = ((analyzer_counter >> blink_shift) & 0x7) == 0x0;
    // Supress LED1 while blinking LED2. We should move them appart on the
    // board such that they don't interfere visually.
    io::LED1.write(blink_state && !led2_counter);

    if (led2_counter > 0 && led2_timer.elapsed_millis() >= 500) {
      led2_timer.reset();
      led2_counter--;
      io::LED2.write(led2_counter > 0 && !(led2_counter & 0x1));
    }

    // if  (reset_flag) {
    //   io::LED2.set();
    // }

    // Check button.
    const uint32_t millis_now = k_uptime_get_32();
    // if (millis_now >= 3000) {
    //   reset_flag = false;
    // }
    Button::ButtonEvent button_event = button::BUTTON1.update(millis_now);
    // if (!button::BUTTON1.is_pressed()) {
    //   // Button is not pressed. Can stop the zero calibration action
    //   feedback. zero_setting = false;
    // }

    if (button_event != Button::EVENT_NONE) {
      printk("Button event: %d\n", button_event);

      // Handle single click. Reverse direction.
      if (button_event == Button::EVENT_SHORT_CLICK) {
        bool new_is_reversed_direcction;
        const bool ok = controls::toggle_direction(&new_is_reversed_direcction);
        const uint16_t num_blinks = !ok                          ? 10
                                    : new_is_reversed_direcction ? 2
                                                                 : 1;
        start_led2_blinks(num_blinks);
      }

      // Handle long press. Zero calibration.
      else if (button_event == Button::EVENT_LONG_PRESS) {
        // zero_setting = true;
        const bool ok = controls::zero_calibration();
        start_led2_blinks(ok ? 3 : 10);
      }
    }

    // This call is blocked until next notification state is available.
    // The rate is fast enough to non interfere with other activities in
    // this loop such as LED blinkin.
    analyzer::pop_next_state(&notification_state, true);

    analyzer_counter++;

    // Send state notification if enabled.
    ble_service::maybe_notify_state(notification_state);

    // printk("Config: %hhu\n",   io::read_hardware_config());
  }
}

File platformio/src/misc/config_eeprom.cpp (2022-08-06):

// Examples:
// https://github.com/zephyrproject-rtos/zephyr/blob/main/samples/drivers/i2c_fujitsu_fram/src/main.c
// https://github.com/zapta/legacy_stepper_motor_analyzer/blob/master/platformio/src/misc/config_eeprom.cpp

#include "config_eeprom.h"

#include <device.h>
#include <drivers/i2c.h>
#include <memory.h>
#include <sys/crc.h>
#include <zephyr.h>

namespace config_eeprom {

static constexpr uint16_t kSettingsCrcAddress = 0x10;
static constexpr uint16_t kSettingsAddress = kSettingsCrcAddress + 4;

// i2c device address.
constexpr uint8_t kEepromDeviceAddress = 0x50;

struct ConfigPayload {
  // Acquisition channels offsets.
  int16_t offset1 = 0;
  int16_t offset2 = 0;
  // Acquisition direction flag.
  bool is_reverse_direction = false;
  // Reserve. Always write as 0.
  uint8_t reserved[32] = {};
};

// sizeof() = 40 as of Jan 2021.
struct ConfigPacket {
  uint32_t crc;
  ConfigPayload payload;
};

// Use this as default package value.
static const ConfigPayload kDefaultConfigPayload = {
    .offset1 = 2970,
    .offset2 = 2070,
    .is_reverse_direction = false,
};

static void clear_reserved(ConfigPayload* payload) {
  memset(&payload->reserved, 0x0, sizeof(payload->reserved));
}

// 'packet.reserved should be pre cleared.
static inline uint32_t compute_crc(const ConfigPayload& payload) {
  // Using an arbitrary seed.
  return crc32_ieee_update(0x1234, reinterpret_cast<const uint8_t*>(&payload),
                           sizeof(payload));
}

bool read_bytes(uint8_t byte_address, uint8_t* bfr, uint8_t size) {
  const struct device* i2c_dev = DEVICE_DT_GET(DT_NODELABEL(i2c0));

  if (!device_is_ready(i2c_dev)) {
    printk("I2c device not ready\n");
    return false;
  }
  int status = i2c_write_read(i2c_dev, kEepromDeviceAddress, &byte_address, 1,
                              bfr, size);

  printk("i2c read: status: %d\n", status);

  return status == 0;
}

bool write_bytes(uint8_t byte_address, const uint8_t* bfr, uint8_t size) {
  const struct device* i2c_dev = DEVICE_DT_GET(DT_NODELABEL(i2c0));

  if (!device_is_ready(i2c_dev)) {
    printk("read_bytes: I2c device not ready\n");
    return false;
  }

  uint8_t bytes_written = 0;

  while (bytes_written < size) {
    // Writes must be in a single 8 bytes page. Determine how many
    // bytes we have to write in the next page.
    const uint8_t next_byte_address = byte_address + bytes_written;
    const uint8_t bytes_left = size - bytes_written;
    uint8_t bytes_in_page = 8 - (next_byte_address & 0x7);
    if (bytes_in_page > bytes_left) {
      bytes_in_page = bytes_left;
    }

    // Preper send buffer. Start address + one to eight bytes to write.
    // bytes_in_page is in the range [1, 8].
    uint8_t packet[1 + 8];
    packet[0] = next_byte_address;
    for (uint8_t i = 0; i < bytes_in_page; i++) {
      packet[i + 1] = bfr[bytes_written++];
    }

    int status =
        i2c_write(i2c_dev, packet, bytes_in_page + 1, kEepromDeviceAddress);

    printk("i2c page write: status: %d\n", status);

    if (status) {
      // last_status = "WRITE_ERROR";
      return false;
    }

    // Let the eeprom finish pending writes, if any. See Twr in the datasheet.
    k_msleep(10);
  }

  return true;
}

static void copy_settings(const ConfigPayload& payload,
                          analyzer::Settings* settings) {
  settings->offset1 = payload.offset1;
  settings->offset2 = payload.offset2;
  settings->is_reverse_direction = payload.is_reverse_direction;
}

// const char* last_status = "NONE";

// Returns true if read ok. Otherwise default settings are returned.
bool read_acquisition_settings(analyzer::Settings* settings) {
  ConfigPacket packet;

  const bool read_ok = read_bytes(0, (uint8_t*)&packet, sizeof(packet));
  if (!read_ok) {
    copy_settings(kDefaultConfigPayload, settings);
    // last_status = "READ-ERROR";
    return false;
  }

  const uint32_t crc = compute_crc(packet.payload);

  printk("Config eeprom CRC: expected %08x, found %08x\n", crc, packet.crc);

  if (crc != packet.crc) {
    printk("Config eeprom: corrupted config, using defaults.\n");
    copy_settings(kDefaultConfigPayload, settings);
    // last_status = "CRC_ERROR";
    return false;
  }

  copy_settings(packet.payload, settings);
  // last_status = "OK";
  return true;
}

// Returns true if written ok.
bool write_acquisition_settings(const analyzer::Settings& settings) {
  ConfigPacket packet;
  // Populate payload.
  packet.payload.offset1 = settings.offset1;
  packet.payload.offset2 = settings.offset2;
  packet.payload.is_reverse_direction = settings.is_reverse_direction;
  clear_reserved(&packet.payload);

  // Compute checkscum.
  packet.crc = compute_crc(packet.payload);

  return write_bytes(0, (uint8_t*)&packet, sizeof(packet));
}

}  // namespace config_eeprom

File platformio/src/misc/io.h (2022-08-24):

#pragma once

#include <hal/nrf_gpio.h>
#include <stdint.h>
#include <zephyr.h>
// #include <misc/button.h>

namespace io {

// --- Output pins

class OutputPin {
 public:
  // Note: Constructor is not called. Seems to be related to the
  // fact we use this as a global var.
  OutputPin() {}

  void init(uint32_t pin_num, uint32_t initial_state) {
    // printk("** OutputPin.init(%u), prior=%u\n", pin_num, pin_num_);
    pin_num_ = pin_num;
    nrf_gpio_cfg_output(pin_num_);
    write(initial_state);
  }
  inline void set() { nrf_gpio_pin_set(pin_num_); }
  inline void clear() { nrf_gpio_pin_clear(pin_num_); }
  inline void toggle() { nrf_gpio_pin_toggle(pin_num_); }
  inline void write(uint32_t val) { nrf_gpio_pin_write(pin_num_, val); }
  inline uint32_t pin_num() { return pin_num_; }

 private:
  // Initialized by init().
  uint32_t pin_num_ = 0;
};

// Active low.
extern OutputPin LED1;
extern OutputPin LED2;

// Output pulses for diagnostics.
extern OutputPin TIMER_OUT_PIN;
extern OutputPin ISR_OUT_PIN;

// Enables power on 0 value.
// extern OutputPin<9> SENSOR_POWER_PIN;

// --- Output pins

class InputPin {
 public:
  InputPin() {}
  void init(uint32_t pin_num, nrf_gpio_pin_pull_t pull) {
    pin_num_ = pin_num;
    nrf_gpio_cfg_input(pin_num_, pull);
  }
  inline bool read() { return nrf_gpio_pin_read(pin_num_); }
  inline bool is_high() { return read(); }
  inline bool is_low() { return !read(); }
  inline uint32_t pin_num() { return pin_num_; }

 private:
  // Initialized by init()
  uint32_t pin_num_ = 0;
};

// Active low. This pin is also the default DFU switch pin
// of MCUboot.
extern InputPin SWITCH1;

// Used to select hardware configuration based on population
// of resistors R11, R12. An installed resistor results in
// '0' at the respective input.
extern InputPin HARDWARE_CFG1;
extern InputPin HARDWARE_CFG2;


void setup();

// Read hardware configuration.
// Returns:
// 3 - R11, R12, not installed.
// 2 - Only R11 installed.
// 1 - Only R12 installed.
// 0 - Both R11, R12 installed.
extern uint8_t read_hardware_config();

}  // namespace io

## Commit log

2022-07-18 Initial public version. No official release yet.
    [MDBT42Q 2D Drawing-20170503.dwg, MDBT42Q 2D Drawing-20170503.dxf, MDBT42Q-P 2D Drawing-20170503.dwg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]
2022-07-18 More PCB cleanup.
    [stepper_probe.kicad_pcb, stepper_probe.sch]
2022-07-19 Generated gerber files.
    [stepper_probe.csv, stepper_probe.kicad_pcb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]
2022-07-19 Generated production files. No tested yet.
    [stepper_probe_bom.csv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]
2022-07-19 Production files with JLCPCB order.
    [stepper_probe.csv, stepper_probe.kicad_pcb, stepper_probe.sch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]
2022-08-02 Updated pin and address to the new JLCPB board.
2022-08-03 Added calibration battery pads.
    [stepper_probe.kicad_pcb, stepper_probe.sch]
2022-08-06 Added support for zero calibration and direction change via the button.
2022-08-06 Freed LED2 for future user feedback.
2022-08-06 Added configuration resistors.
    [stepper_probe.kicad_pcb, stepper_probe.sch]
2022-08-06 Moved SOIC footprint to local library. Before rotating for JLCPCB.
    [stepper_probe.kicad_pcb, stepper_probe.sch]
2022-08-06 Rotated footprints for JLCPCB orientation.
    [stepper_probe.csv, stepper_probe.kicad_pcb, stepper_probe.sch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]
2022-08-08 Assorted tweaks.
    [stepper_probe.kicad_pcb, stepper_probe.sch, stepper_probe_case.stl]
2022-08-08 Added the stepper connectors to JLCPCB files.
    [stepper_probe.csv, stepper_probe.kicad_pcb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]
2022-08-08 Added stepper connectors to JLCPCB list.
    [stepper_probe.kicad_pcb]
2022-08-09 Minor cleanup.
    [stepper_probe_case.stl]
2022-08-10 Work in progress.
    [stepper_probe.kicad_pcb, stepper_probe.sch]
2022-08-13 Minor clean ups.
    [stepper_probe.csv, stepper_probe.kicad_pcb, stepper_probe.sch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]
2022-08-13 Cleaned up power in header.
    [stepper_probe.csv, stepper_probe.kicad_pcb, stepper_probe.sch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]
2022-08-13 Generated gervers.
    [stepper_probe.csv]
2022-08-13 Minor change of 'DNI' to 'DNP' for consistency.
    [stepper_probe.kicad_pcb, stepper_probe.sch]
2022-08-14 Added zener protection
    [stepper_probe.csv, stepper_probe.kicad_pcb, stepper_probe.sch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]
2022-08-14 Generated JLCPCB gerber files.
    [stepper_probe.csv, stepper_probe.kicad_pcb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]
2022-08-14 Updated TODO, added noise analysis.
    [steps_noise_TMCS1108.xlsx]
2022-08-14 Fixed a few TODOs.
    [ble_service.cpp, probe.py]
2022-08-15 Added UI feedback via LED2.
2022-08-15 Minor PCB tweaks, moved LEDs, added pin 1 marks, added zenner silk screen. No electrical or bom change.
    [stepper_probe.kicad_pcb]
2022-08-16 Added BLE command for direction toggle and zero calibration.
    [stepper_probe.sch]
2022-08-20 Added sensors selection logic. Tweaked the python client.
    [stepper_probe.sch, stepper_probe_case.stl]
2022-08-24 Inverted the hardware config code.
    [io.h, main.cpp]
2022-08-26 Cleaned up the event loop.
    [ble_stepper_analyzer_case.stl, stepper_probe_case.stl]
2022-08-26 Added requirements files. Remove initial delayed. Reduced timer interval from 25ms to 20ms.
2022-08-28 Assorted tweaks and fixes.
    [ble_stepper_analyzer_case.stl]
2022-08-28 Now using average for zero calibration. Also updated README and Kicad.
    [stepper_probe.kicad_pcb, stepper_probe.sch]
2022-08-28 Fixed nrf52 footprint.
    [stepper_probe.kicad_pcb]
2022-08-31 Added 3 pins header to the JLCPCB BOM.
    [stepper_probe.kicad_pcb]
2022-08-31 Flushing open files.
    [stepper_probe.sch]
2022-09-06 Upgraded to kicad 6
    [ble_stepper_analyzer_case.stl, stepper_probe.kicad_pcb, stepper_probe.kicad_sch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]
2022-09-07 Cleaned up kicad 6 files.
    [stepper_probe.kicad_pcb, stepper_probe.kicad_sch, stepper_probe.sch]
2022-09-18 Minor kicad tweaks.
2022-09-18 Added print messages for debugging.
2022-09-24 Added additional debug markers to probe.py
2022-10-02 Added a test case for Bleak's connection.
2022-10-23 Changed the initialization order. Now first connecting to the device and then initializing pyqtgraph UI. This will make the initialization sequence closer to the one in the bleak test program which w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
2022-10-23 Now printing os and python info on start.
